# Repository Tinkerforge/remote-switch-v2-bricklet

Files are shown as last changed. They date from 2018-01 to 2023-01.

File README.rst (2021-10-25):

Remote Switch Bricklet 2.0
==========================

This repository contains the firmware source code and the hardware design
files. The documentation generator configs can be found at
https://github.com/Tinkerforge/generators

Repository Content
------------------

software/:
 * examples/: Examples for all supported languages
 * build/: Compiled files
 * src/: Source code of firmware
 * Makefile: Makefile to build project

hardware/:
 * Contains KiCad project files and additionally schematics as PDF

datasheets/:
 * Contains datasheets for sensors and complex ICs that are used

Hardware
--------

The hardware is designed with the open source EDA Suite KiCad
(http://www.kicad.org). Before you are able to open the files,
you have to install the Tinkerforge kicad-libraries
(https://github.com/Tinkerforge/kicad-libraries). You can either clone
them directly in hardware/ or clone them in a separate folder and
symlink them into hardware/
(ln -s kicad_path/kicad-libraries project_path/hardware). After that you
can open the .pro file in hardware/ with KiCad and from there view and
modify the schematics and the PCB layout.

Software
--------

If you want to do your own Brick/Bricklet firmware development we highly
recommend that you use our build environment setup script and read the
tutorial (https://www.tinkerforge.com/en/doc/Tutorials/Tutorial_Build_Environment/Tutorial.html).

To compile the C code we recommend you to install the newest GNU Arm Embedded
Toolchain (https://launchpad.net/gcc-arm-embedded/+download).
You also need to install bricklib2 (https://github.com/Tinkerforge/bricklib2).

You can either clone it directly in software/src/ or clone it in a
separate folder and symlink it into software/src/
(ln -s bricklib_path/bricklib2 project_path/software/src/). Finally make sure to
have CMake installed (http://www.cmake.org/cmake/resources/software.html).

After that you can build the firmware by invoking make in software/.
The firmware (.zbin) can then be found in software/build/ and uploaded
with brickv (click button "Flashing" on start screen).

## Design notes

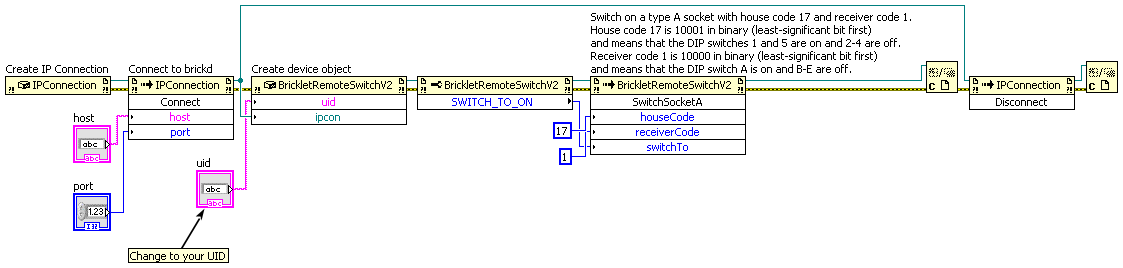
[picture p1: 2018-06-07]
software/examples/labview/Example Switch Socket.vi.png

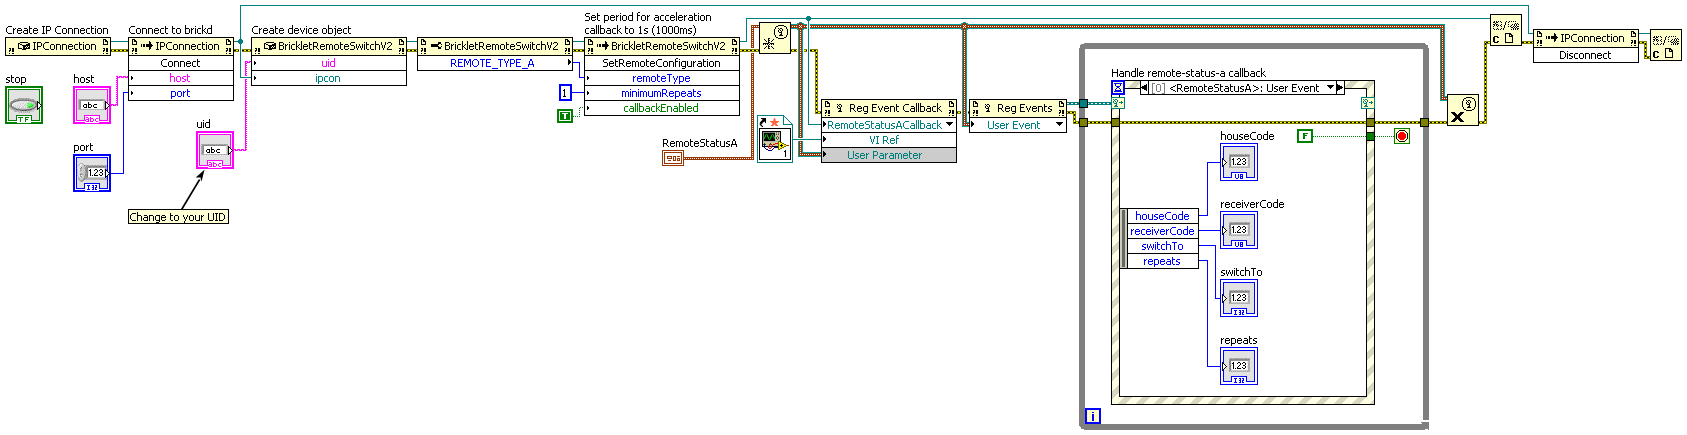
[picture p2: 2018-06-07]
software/examples/labview/Example Remote Callback.vi.png

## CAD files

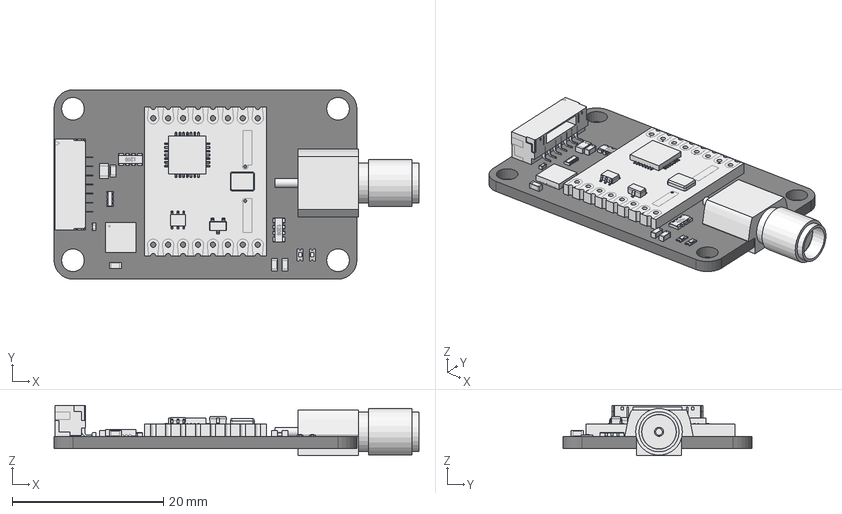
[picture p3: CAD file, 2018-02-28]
hardware/remote-switch-v2.FCStd
48.2 x 25.0 x 6.64 mm
Pcb
C_0402_
C_0603_
C_0603_001
C_0603_002
C_0603_003
BrickletConn_7pin_
R_4x0603_
QFN-24_4x4mm_Pitch0.5mm_
R_4x0603_001
C_0805_
Remote_Modul_
FT-004B_
D_0603_blue_

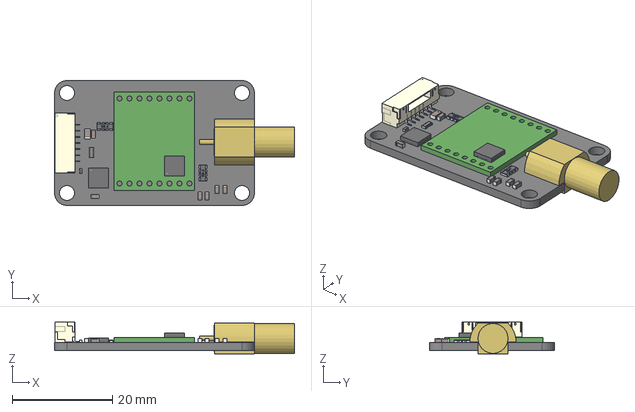
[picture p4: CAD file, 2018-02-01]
hardware/remote.step
48.0 x 25.0 x 6.37 mm

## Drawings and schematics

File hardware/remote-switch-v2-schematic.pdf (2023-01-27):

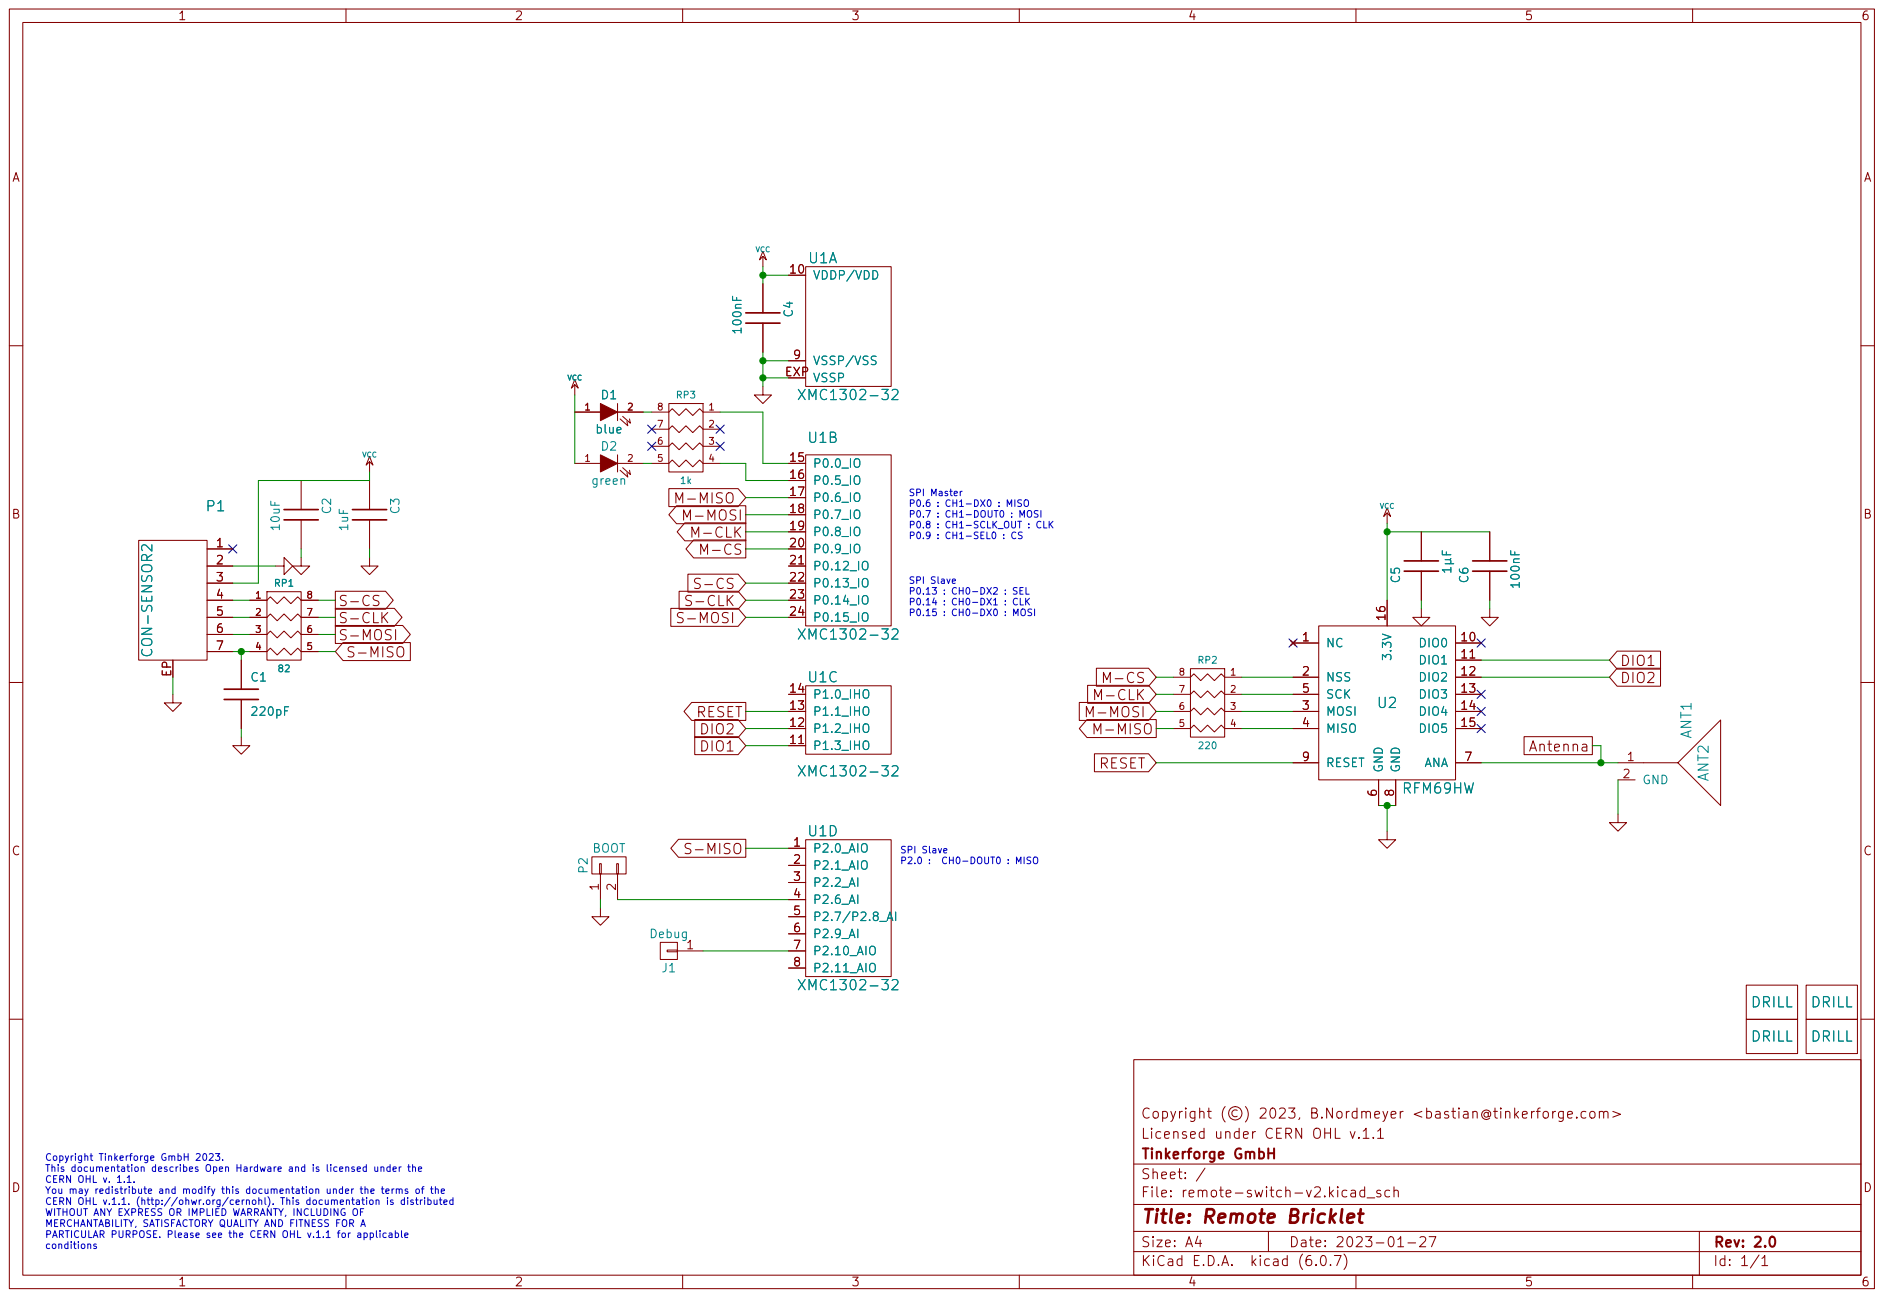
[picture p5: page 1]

P0.15 : CH0-DX0 : MOSI SPI Master P0.6 : CH1-DX0 : MISO

SPI Slave P0.13 : CH0-DX2 : SEL P0.14 : CH0-DX1 : CLK

Licensed under CERN OHL v.1.1
File: remote-switch-v2.kicad_sch Sheet: / Tinkerforge GmbH

Copyright Tinkerforge GmbH 2023. This documentation describes Open Hardware and is licensed under the CERN OHL v. 1.1. You may redistribute and modify this documentation under the terms of the CERN OHL v.1.1. (http://ohwr.org/cernohl). This documentation is distributed WITHOUT ANY EXPRESS OR IMPLIED WARRANTY, INCLUDING OF MERCHANTABILITY, SATISFACTORY QUALITY AND FITNESS FOR A

Id: 1/1 Title: Remote Bricklet

PARTICULAR PURPOSE. Please see the CERN OHL v.1.1 for applicable

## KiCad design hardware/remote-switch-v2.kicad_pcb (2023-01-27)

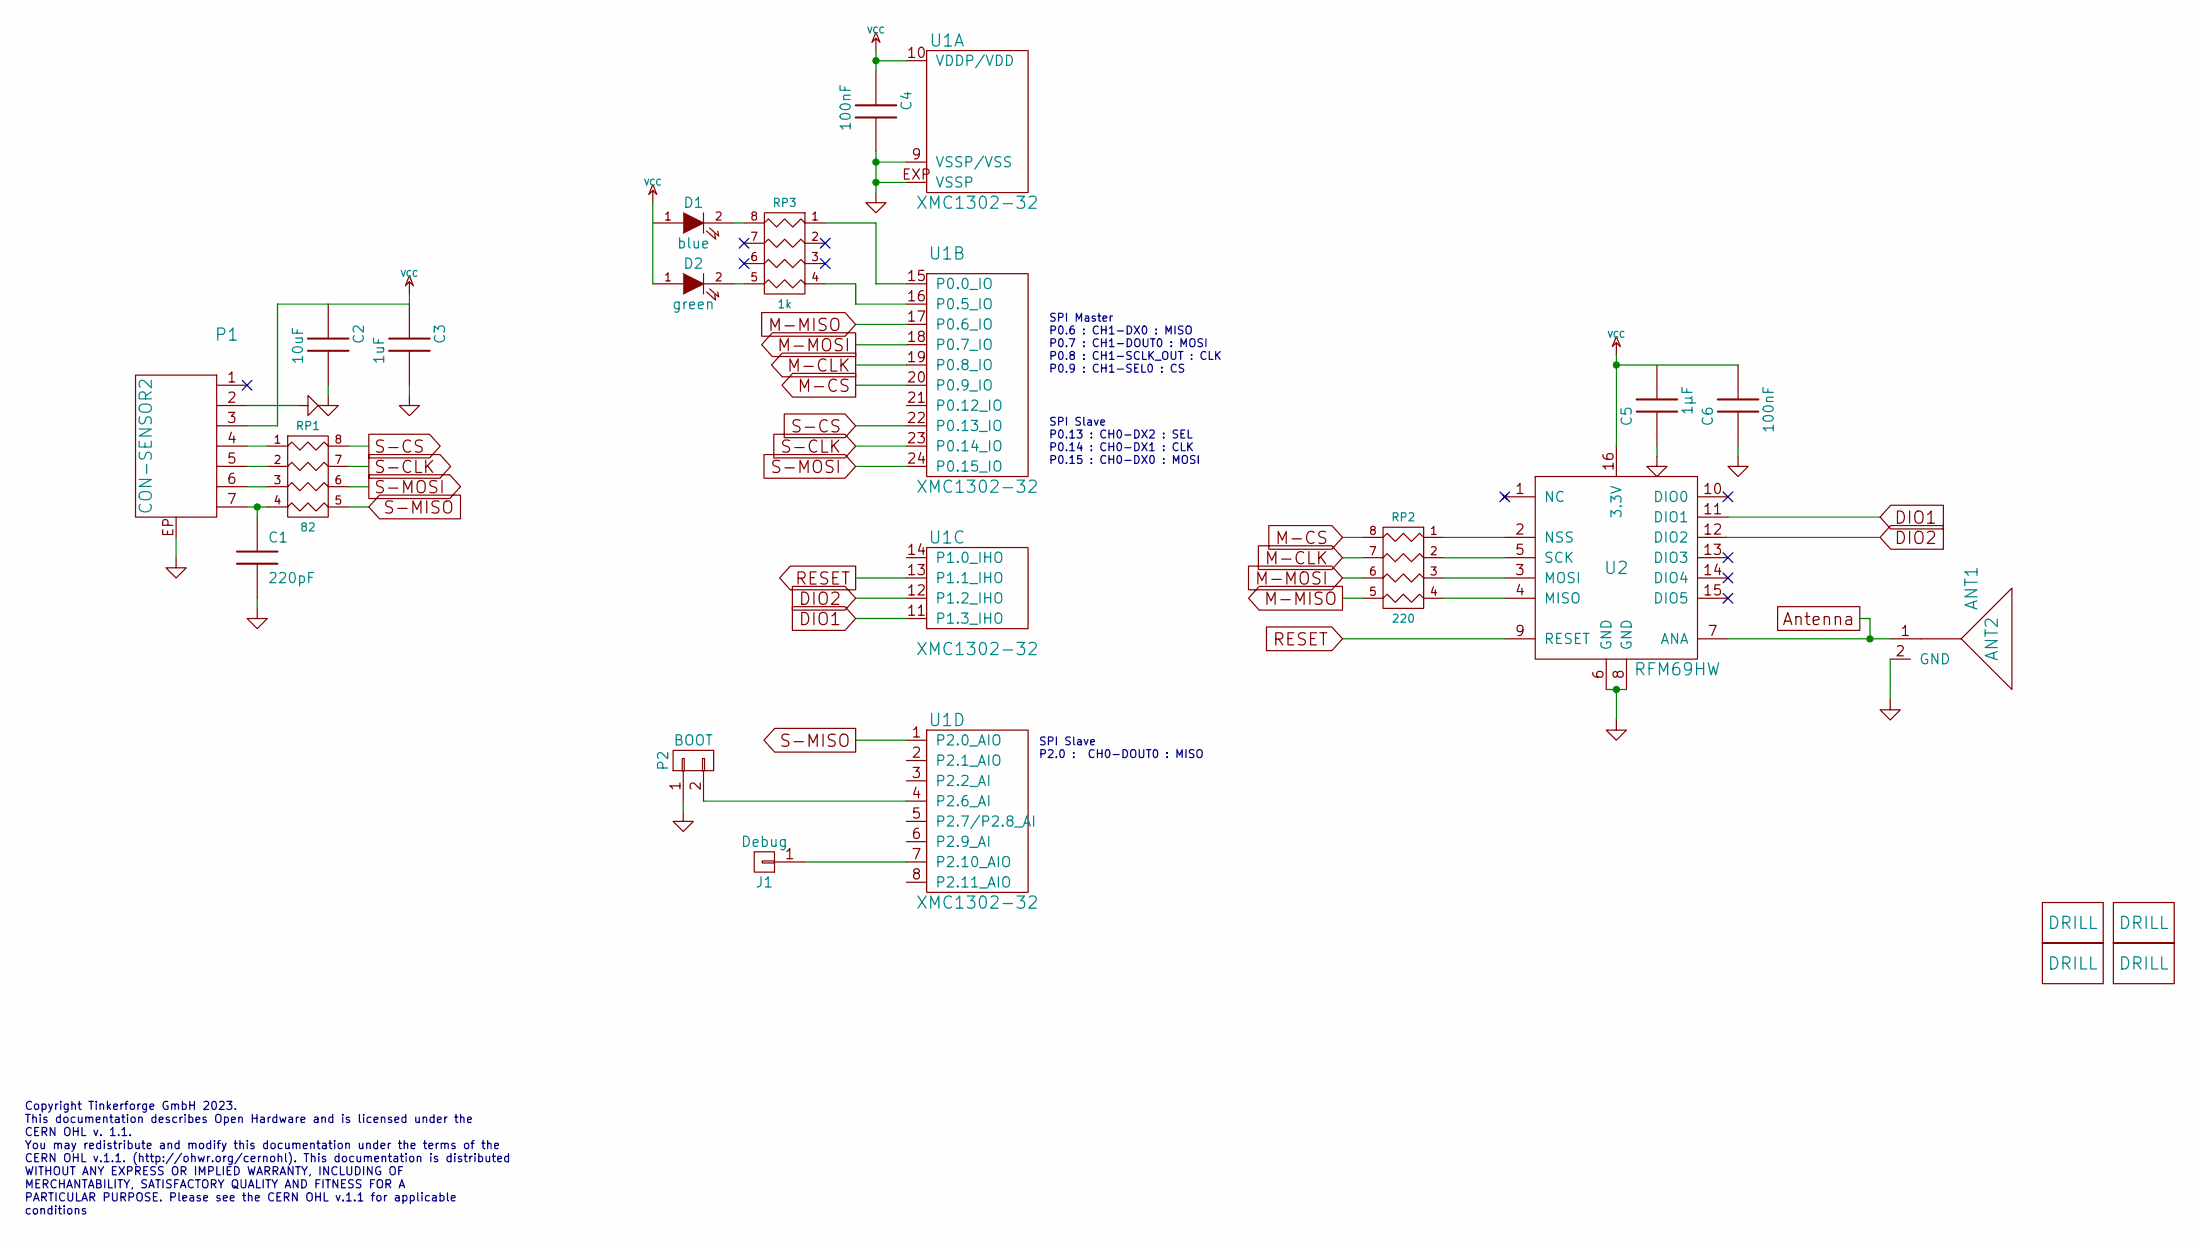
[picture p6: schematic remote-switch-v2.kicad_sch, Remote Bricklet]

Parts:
ANT1: ANT2; FT-004B
C1: 220pF; C0402F
C2: 10uF; C0805
C3: 1uF; C0603F
C4, C6: 100nF; C0603F
C5: 1µF; C0603F
D1: blue; D0603F
D2: green; D0603F
J1: Debug; DEBUG_PAD
P1: CON-SENSOR2
P2: BOOT; SolderJumper
RP1: 82; 4X0402
RP2: 220; 4X0603
RP3: 1k; 4X0603
U1: XMC1302-32; QFN24-4x4mm-0.5mm
U2: RFM69HW
U3, U4, U5, U6: DRILL; DRILL_NP

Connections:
Antenna: ANT1.1, U2.7 (ANA)
DIO1: U1.11 (P1.3_IHO), U2.11 (DIO1)
DIO2: U1.12 (P1.2_IHO), U2.12 (DIO2)
GND: ANT1.2 (GND), C1.2, C2.2, C3.2, C4.2, C5.1, C6.1, P1.2, P1.EP, P2.1, U1.9 (VSSP/VSS), U1.EXP (VSSP), U2.6 (GND), U2.8 (GND)
M-CLK: RP2.7 (R2), U1.19 (P0.8_IO)
M-CS: RP2.8 (R1), U1.20 (P0.9_IO)
M-MISO: RP2.5 (R4), U1.17 (P0.6_IO)
M-MOSI: RP2.6 (R3), U1.18 (P0.7_IO)
unnamed: C1.1, P1.7, RP1.4
unnamed: D1.2 (K), RP3.8 (R1)
unnamed: D2.2 (K), RP3.5 (R4)
unnamed: J1.1, U1.7 (P2.10_AIO)
unnamed: P1.4, RP1.1
unnamed: P1.5, RP1.2
unnamed: P1.6, RP1.3
unnamed: P2.2, U1.4 (P2.6_AI)
unnamed: RP2.1, U2.2 (NSS)
unnamed: RP2.2, U2.5 (SCK)
unnamed: RP2.3, U2.3 (MOSI)
unnamed: RP2.4, U2.4 (MISO)
unnamed: RP3.1, U1.15 (P0.0_IO)
unnamed: RP3.4, U1.16 (P0.5_IO)
RESET: U1.13 (P1.1_IHO), U2.9 (RESET)
S-CLK: RP1.7 (R2), U1.23 (P0.14_IO)
S-CS: RP1.8 (R1), U1.22 (P0.13_IO)
S-MISO: RP1.5 (R4), U1.1 (P2.0_AIO)
S-MOSI: RP1.6 (R3), U1.24 (P0.15_IO)
VCC: C2.1, C3.1, C4.1, C5.2, C6.2, D1.1 (A), D2.1 (A), P1.3, U1.10 (VDDP/VDD), U2.16 (3.3V)

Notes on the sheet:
SPI Slave P0.13 : CH0-DX2 : SEL P0.14 : CH0-DX1 : CLK P0.15 : CH0-DX0 : MOSI
Copyright Tinkerforge GmbH 2023. This documentation describes Open Hardware and is licensed under the CERN OHL v. 1.1. You may redistribute and modify this documentation under the terms of the CERN OHL v.1.1. (http://ohwr.org/cernohl). This documentation is distributed WITHOUT ANY EXPRESS OR IMPLIE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
SPI Master P0.6 : CH1-DX0 : MISO P0.7 : CH1-DOUT0 : MOSI P0.8 : CH1-SCLK_OUT : CLK P0.9 : CH1-SEL0 : CS
SPI Slave P2.0 : CH0-DOUT0 : MISO

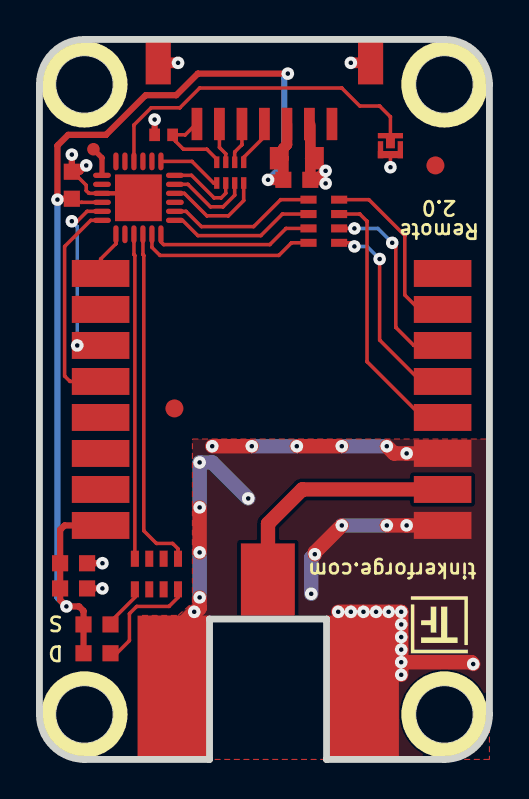
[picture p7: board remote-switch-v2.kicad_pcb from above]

Board: 2 copper layers, 25.0 x 40.0 mm, 25 parts (2 on the bottom side), 28 nets.

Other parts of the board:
Fiducial_Mark: VAL**; Fiducial_Mark
Fiducial_Mark#2: VAL**; Fiducial_Mark
VAL: CE_5mm
VAL#2: WEEE_7mm

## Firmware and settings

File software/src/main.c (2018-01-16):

/* remote-switch-v2-bricklet
 * Copyright (C) 2017 Olaf Lüke <olaf@tinkerforge.com>
 *
 * main.c: Initialization for Remote Switch V2 Bricklet
 *
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
 * You should have received a copy of the GNU Lesser General Public
 * License along with this library; if not, write to the
 * Free Software Foundation, Inc., 59 Temple Place - Suite 330,
 * Boston, MA 02111-1307, USA.
 */

#include <stdio.h>
#include <stdbool.h>

#include "configs/config.h"

#include "bricklib2/bootloader/bootloader.h"
#include "bricklib2/hal/system_timer/system_timer.h"
#include "bricklib2/logging/logging.h"
#include "communication.h"
#include "rfm69.h"


int main(void) {
	logging_init();
	logd("Start Remote Switch Bricklet 2.0\n\r");

	communication_init();
	rfm69_init();

	while(true) {
		bootloader_tick();
		communication_tick();
		rfm69_tick();
	}
}

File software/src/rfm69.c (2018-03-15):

/* remote-switch-v2-bricklet
 * Copyright (C) 2017 Olaf Lüke <olaf@tinkerforge.com>
 *
 * rfm69.c: RFM69 ISM transceiver driver
 *
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
 * You should have received a copy of the GNU Lesser General Public
 * License along with this library; if not, write to the
 * Free Software Foundation, Inc., 59 Temple Place - Suite 330,
 * Boston, MA 02111-1307, USA.
 */

#include "rfm69.h"

#include <string.h>

#include "configs/config_rfm69.h"

#include "bricklib2/logging/logging.h"
#include "bricklib2/os/coop_task.h"
#include "xmc_gpio.h"
#include "xmc_spi.h"

#include "communication.h"

CoopTask rfm69_task;
RFM69 rfm69;

#define rfm69_rx_irq_handler IRQ_Hdlr_11
#define rfm69_tx_irq_handler IRQ_Hdlr_12

const uint8_t rfm69_config_general[][2] = {
	{REG_FRFMSB, RF_FRFMSB_433_92}, // 433.92 Mhz
	{REG_FRFMID, RF_FRFMID_433_92},
	{REG_FRFLSB, RF_FRFLSB_433_92},
	{REG_RXBW, RF_RXBW_DCCFREQ_010 | RF_RXBW_MANT_24},
	{REG_DATAMODUL, RF_DATAMODUL_DATAMODE_PACKET | RF_DATAMODUL_MODULATIONTYPE_OOK | RF_DATAMODUL_MODULATIONSHAPING_00}, // Use OOK
	{REG_BITRATEMSB, TYPE_A_C_BITRATEMSB},
	{REG_BITRATELSB, TYPE_A_C_BITRATELSB},
	{REG_PREAMBLEMSB, 0x00}, // no preamble
	{REG_PREAMBLELSB, 0x00},
	{REG_SYNCCONFIG, RF_SYNC_OFF | RF_SYNC_FIFOFILL_MANUAL}, // Use empty sync to assure small pause between commands
	{REG_SYNCVALUE1, 0},
	{REG_SYNCVALUE2, 0},
	{REG_SYNCVALUE3, 0},
	{REG_SYNCVALUE4, 0},
	{REG_SYNCVALUE5, 0},
	{REG_SYNCVALUE6, 0},
	{REG_SYNCVALUE7, 0},
	{REG_SYNCVALUE8, 0},
	{REG_PACKETCONFIG1, RF_PACKET1_FORMAT_FIXED | RF_PACKET1_DCFREE_OFF | RF_PACKET1_CRC_OFF},
	{REG_PAYLOADLENGTH, 0},
	{REG_FIFOTHRESH, RF_FIFOTHRESH_TXSTART_FIFONOTEMPTY}, // Set fifo threshold, send when threshold reached
	{REG_PALEVEL, RF_PALEVEL_OUTPUTPOWER_11111},
	{REG_DIOMAPPING1, 0b00000000},
	{REG_DIOMAPPING2, 0b00010111},
	{REG_LNA, RF_LNA_ZIN_50 | RF_LNA_GAINSELECT_AUTO},
	{REG_ENDOFCONFIG, 0}
};

const uint8_t rfm69_config_receive[][2] = {
	{REG_PACKETCONFIG1, RF_PACKET1_FORMAT_FIXED | RF_PACKET1_DCFREE_OFF | RF_PACKET1_CRC_OFF},
	{REG_PAYLOADLENGTH, 0},
	{REG_PALEVEL, RF_PALEVEL_OUTPUTPOWER_11111}, // disable amplifier (otherwise we can't receive)
	{REG_OCP, RF_OCP_ON | RF_OCP_TRIM_95}, // OCP on
	{REG_TESTPA1, 0x55}, // Disable high power mode (only in hw version)
	{REG_TESTPA2, 0x70}, // Disable high power mode (only in hw version)
	{REG_ENDOFCONFIG, 0}
};

const uint8_t rfm69_config_transmit[][2] = {
	{REG_PACKETCONFIG1, RF_PACKET1_FORMAT_VARIABLE | RF_PACKET1_DCFREE_OFF | RF_PACKET1_CRC_OFF},
	{REG_PALEVEL, RF_PALEVEL_OUTPUTPOWER_11111 | RF_PALEVEL_PA1_ON | RF_PALEVEL_PA2_ON}, // w/ power amplifier: PA 1 and 2 on, 20dBm
	{REG_OCP, RF_OCP_OFF | RF_OCP_TRIM_120}, // OCP off, trimming at 120mA
	{REG_TESTPA1, 0x5D}, // High power mode (only in hw version)
	{REG_TESTPA2, 0x7C}, // High power mode (only in hw version)
	{REG_ENDOFCONFIG, 0}
};

const uint8_t rfm69_type_registers_transmit[NUM_TYPE_CONFIGURATIONS] = {
	REG_BITRATEMSB,
	REG_BITRATELSB,
	REG_PAYLOADLENGTH,
};

const uint8_t rfm69_type_configurations_transmit[NUM_TYPES][NUM_TYPE_CONFIGURATIONS] = {
	{TYPE_A_C_BITRATEMSB, TYPE_A_C_BITRATELSB, TYPE_A_C_PACKET_LENGTH},
	{TYPE_B_BITRATEMSB, TYPE_B_BITRATELSB, TYPE_B_PACKET_LENGTH},
	{TYPE_B_BITRATEMSB, TYPE_B_BITRATELSB, TYPE_B_DIM_PACKET_LENGTH},
};


void __attribute__((optimize("-O3"))) rfm69_rx_irq_handler(void) {
	while(!XMC_USIC_CH_RXFIFO_IsEmpty(RFM69_USIC)) {
		rfm69.data_spi[rfm69.data_read_index] = RFM69_USIC->OUTR;
		rfm69.data_read_index++;
	}
}

void __attribute__((optimize("-O3"))) rfm69_tx_irq_handler(void) {
	while(!XMC_USIC_CH_TXFIFO_IsFull(RFM69_USIC)) {
		RFM69_USIC->IN[0] = rfm69.data_spi[rfm69.data_write_index];
		rfm69.data_write_index++;
		if(rfm69.data_write_index >= rfm69.data_length) {
			XMC_USIC_CH_TXFIFO_DisableEvent(RFM69_USIC, XMC_USIC_CH_TXFIFO_EVENT_CONF_STANDARD);
			return;
		}
	}
}

void rfm69_task_spi_transceive(void) {
	XMC_SPI_CH_EnableSlaveSelect(RFM69_USIC, XMC_SPI_CH_SLAVE_SELECT_0);
	XMC_USIC_CH_TXFIFO_EnableEvent(RFM69_USIC, XMC_USIC_CH_TXFIFO_EVENT_CONF_STANDARD);
	XMC_USIC_CH_TriggerServiceRequest(RFM69_USIC, RFM69_SERVICE_REQUEST_TX);

	while(rfm69.data_read_index < rfm69.data_length) {
		rfm69_rx_irq_handler();
		coop_task_yield();
	}

	XMC_SPI_CH_DisableSlaveSelect(RFM69_USIC);
}

void rfm69_task_read_register(const uint8_t reg, uint8_t *data, const uint8_t length) {
	rfm69.data_read_index  = 0;
	rfm69.data_write_index = 0;
	rfm69.data_spi[0] = reg;
	for(uint16_t i = 0; i < length; i++) {
		rfm69.data_spi[i+1] = reg + 1 + i;
	}

	rfm69.data_length = length + 1;

	rfm69_task_spi_transceive();

	memcpy(data, &rfm69.data_spi[1], length);
}

void rfm69_task_write_register(const uint8_t reg, const uint8_t *data, const uint8_t length) {
	rfm69.data_read_index  = 0;
	rfm69.data_write_index = 0;
	rfm69.data_spi[0] = reg | REG_WRITE;
	memcpy(&rfm69.data_spi[1], data, length);

	rfm69.data_length = length + 1;

	rfm69_task_spi_transceive();
}

void rfm69_task_configure_receive(void) {
	// Set general receive config
	for(uint8_t i = 0; rfm69_config_receive[i][0] != REG_ENDOFCONFIG; i++) {
		rfm69_task_write_register(rfm69_config_receive[i][0], &rfm69_config_receive[i][1], 1);
	}

	// Set bitrate in correspondence with remote type
	uint8_t bitrate_data;
	switch(rfm69.remote_type) {
		case REMOTE_SWITCH_V2_REMOTE_TYPE_A: bitrate_data = TYPE_A_RECV_BITRATEMSB; break;
		case REMOTE_SWITCH_V2_REMOTE_TYPE_B: bitrate_data = TYPE_B_RECV_BITRATEMSB; break;
		case REMOTE_SWITCH_V2_REMOTE_TYPE_C: bitrate_data = TYPE_C_RECV_BITRATEMSB; break;
		default: bitrate_data = TYPE_A_RECV_BITRATEMSB; break;
	}
	rfm69_task_write_register(REG_BITRATEMSB, &bitrate_data, 1);

	switch(rfm69.remote_type) {
		case REMOTE_SWITCH_V2_REMOTE_TYPE_A: bitrate_data = TYPE_A_RECV_BITRATELSB; break;
		case REMOTE_SWITCH_V2_REMOTE_TYPE_B: bitrate_data = TYPE_B_RECV_BITRATELSB; break;
		case REMOTE_SWITCH_V2_REMOTE_TYPE_C: bitrate_data = TYPE_C_RECV_BITRATELSB; break;
		default: bitrate_data = TYPE_A_RECV_BITRATELSB; break;
	}
	rfm69_task_write_register(REG_BITRATELSB, &bitrate_data, 1);


	// Change to standby mode
	uint8_t data_opmode;
	rfm69_task_read_register(REG_OPMODE, &data_opmode, 1);
	while(!(data_opmode & RF_OPMODE_STANDBY)) {
		uint8_t data_irqflags2;
		rfm69_task_read_register(REG_IRQFLAGS2, &data_irqflags2, 1);
		if((data_opmode != RF_OPMODE_TRANSMITTER) || (!(data_irqflags2 & RF_IRQFLAGS2_FIFONOTEMPTY))) {
			uint8_t data = RF_OPMODE_STANDBY;
			rfm69_task_write_register(REG_OPMODE, &data, 1);
		}

		rfm69_task_read_register(REG_OPMODE, &data_opmode, 1);
	}

	// Enable receiver
	uint8_t data = RF_OPMODE_RECEIVER;
	rfm69_task_write_register(REG_OPMODE, &data, 1);

	// Wait for receiver to be ready
	uint8_t data_irqflags1 = 0;
	do {
		rfm69_task_read_register(REG_IRQFLAGS1, &data_irqflags1, 1);
	} while(!(data_irqflags1 & RF_IRQFLAGS1_RXREADY));


	// Reset command data
	rfm69.data_receive_command_bit = 0;
	rfm69.data_receive_command_new = 0;
}
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

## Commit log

2017-09-05 Add initial stub version
    [cmake_config_custom.txt]
2017-09-13 major parts of remote switch bricklet v2 schematic finished
    [remote.sch]
2017-09-13 add dio signals
    [remote.sch]
2017-09-14 finished prototype
    [remote.kicad_pcb, remote.sch]
2017-09-18 fix capacitor footprints
    [remote.kicad_pcb, remote.sch]
2017-09-28 fix bootpad name
    [remote.kicad_pcb, remote.sch]
2017-09-28 specify processor
    [remote.kicad_pcb, remote.sch]
2017-09-28 add debug pad
    [remote.kicad_pcb, remote.sch]
2017-09-29 Change MCU to XMC1300
    [cmake_config_custom.txt]
2017-09-29 Use led for debug
2017-09-29 Set pins as used in production board
2017-10-26 move text to fab layer
    [remote.kicad_pcb]
2017-11-24 specify led colors
    [remote.kicad_pcb, remote.sch]
2018-01-15 examples: Add missing remote config call
    [example_remote_callback.c]
2018-01-16 Return empty configuration if the remote type is not currently configured
2018-01-16 Use correct slave select (0 instead of 4)
    [rfm69.c]
2018-01-25 fix broken mounting holes
    [remote.kicad_pcb]
2018-01-26 c: Fine-tune printf format
2018-02-01 Fix egde cuts
    [remote.kicad_pcb]
2018-02-01 Add 3d information (final)
    [remote.kicad_pcb]
2018-02-01 Add 3d model (*.step & *.FCStd)
    [remote.FCStd, remote.step]
2018-02-16 Fix symbol (CONN_01X01)
    [remote.sch]
2018-02-16 Add schematic PDF
2018-02-20 Cleanup KiCad libraries config
    Ensure LibDir=kicad-libraries and LibName1=tinkerforge.
    Remove special library.
2018-02-28 Add new 3d model with more detailed components
    [remote.FCStd, remote.kicad_pcb]
2018-03-02 Fix outline from antenna connector larger caused thru production tolerance
    [remote.kicad_pcb]
2018-03-15 RFM69 expects passive level 0 spi
2018-05-11 Rename files
    [remote-switch-v2.FCStd, remote-switch-v2.kicad_pcb, remote-switch-v2.sch]
2018-06-18 Change capacitor footprint(s) to C0402F
    [remote-switch-v2.kicad_pcb, remote-switch-v2.sch]
2018-12-20 Fix constant handling in examples.
    [example_remote_callback.c]
2019-08-22 c: Adapt to bindings changes
    [example_remote_callback.c]
2020-08-31 uc: Use fixed-with placeholders in format strings.
    [example_remote_callback.c]
2020-09-02 uc: Add example driver note.
2021-10-25 Update KiCad link
    https://www.kicad.org/blog/2021/10/Avoid-links-to-former-kicad-domain/
2022-04-27 uc: Adapt to bindings changes
    [example_remote_callback.c]
2023-01-27 fix schamtic
    [remote-switch-v2.kicad_sch, remote-switch-v2.sch]
2023-01-27 Data Cleanup
    [remote-switch-v2.kicad_pcb, remote-switch-v2.kicad_sch]

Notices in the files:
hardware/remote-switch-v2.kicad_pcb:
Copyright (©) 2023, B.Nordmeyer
